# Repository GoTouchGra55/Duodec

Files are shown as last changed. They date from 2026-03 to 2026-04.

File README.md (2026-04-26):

# Duodec





A 12-key + 1 rotary encoder macropad built on
the RP2040-Zero, designed for developers and
students who live in their terminal.

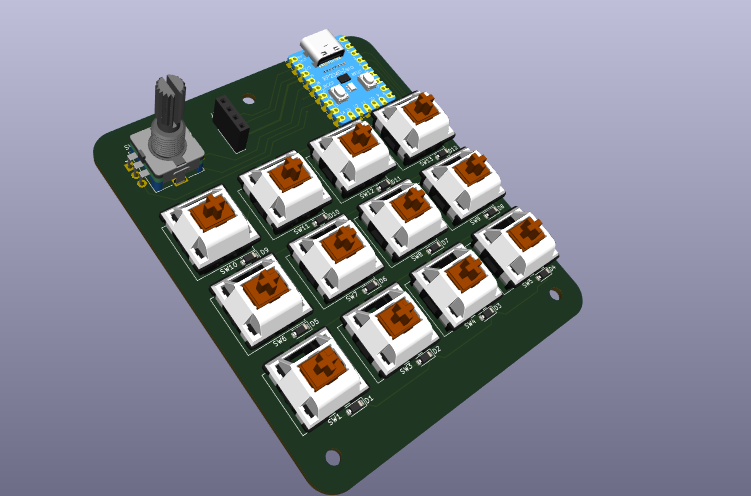
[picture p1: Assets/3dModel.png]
Duodec 3d model


---

## Overview

**Duodec** (Latin: _twelve_) is a compact, open-source macropad featuring 12 mechanical switches, a clickable rotary encoder, and an 128x32 OLED display. Built around the RP2040-Zero, it's fully programmable in Python.

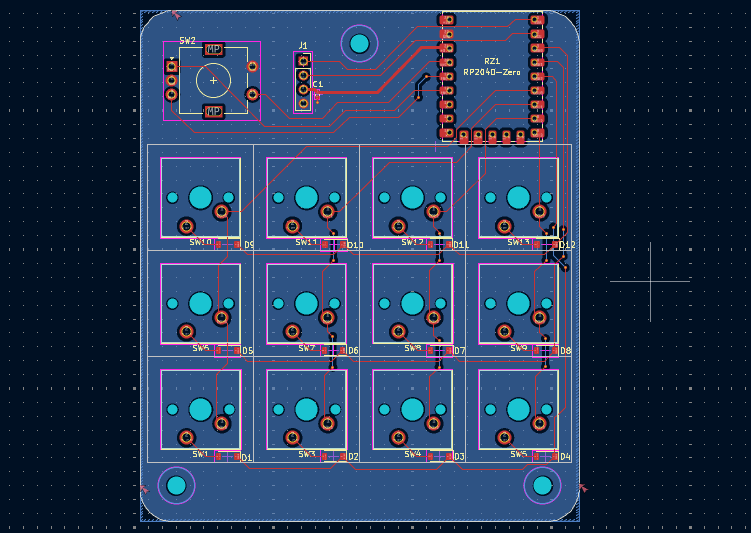
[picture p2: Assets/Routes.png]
PCB traces

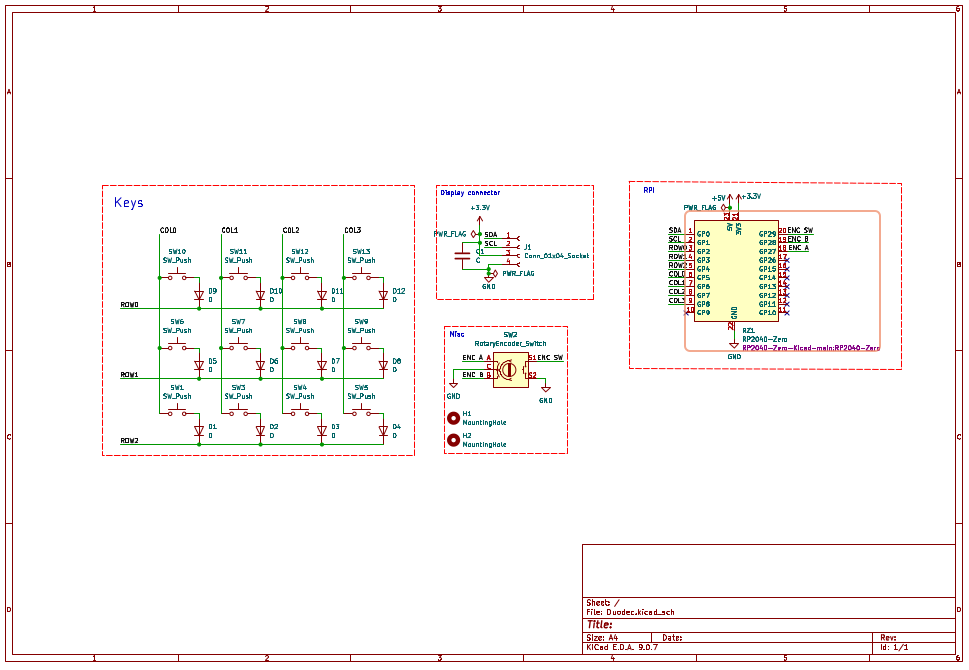
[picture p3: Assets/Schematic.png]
Schematic


---

## Working Demo

Here’s a quick demonstration of Duodec in action, showing key inputs, encoder rotation, and OLED layer switching.

Duodec demo

---

## Features

- 12x mechanical key switches in a 4x3 matrix
- 1x rotary encoder with push-button click
- 128x32 OLED display
- RP2040-Zero (RP2040 chip, USB-C)
- Fully programmable in Python
- Multiple layers for different workflows
- Custom 3D printed keys
- Open source hardware and software

## ⚠️ Important Wiring Note
Sorry about this ;-; but the OLED display requires **2-4kΩ 3.3V pull-up resistors** on both:
- SDA (I2C data line)
- SCL (I2C clock line)

Without these, the display will not function at all.

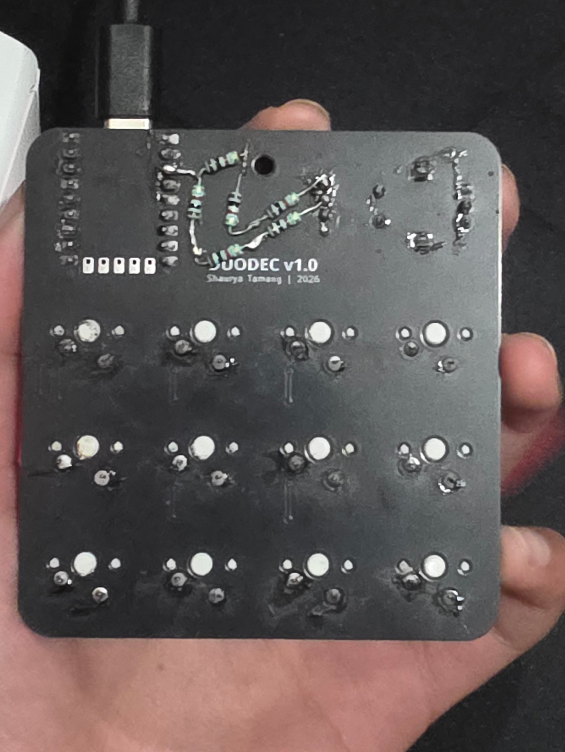
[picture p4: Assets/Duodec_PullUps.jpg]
PullUp Resistors


## Customization

1. Clone this repository
2. Open `src/main.py`
3. Modify keymaps (line 26)
4. Add your own shortcuts and layers
5. Flash to your RP2040-Zero

Be productive 🚀

## Contributing

Contributions are welcome!

If you'd like to improve Duodec, you can:
- Suggest new features or workflows
- Improve firmware or add new layers
- Fix bugs or optimize performance
- Enhance documentation or visuals

Please open an issue first to discuss major changes.

Pull requests should be clean, well-documented, and tested where possible.

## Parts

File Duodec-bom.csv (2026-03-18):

Name | Purpose | Cost Per Item (USD) | Quantity | Total (USD) | Link | Distributor
LEOBOG Graywood V4 Mechanical Linear Switch (Pack of 10) | To take user input in the deck | 3.39 | 2 | 6.78 | https://www.daraz.com.np//products/i170535424-s1189144506.html?urlFlag=true | Daraz Nepal
PCB and 3d Parts | PCB is the backbone for duodec and the 3d printed parts are for protection and ease of use | 17.59 | 1 | 17.59 | https://jlc3dp.com/shopcart/cart?source=3D&spm=Jlc3dp.Homepage.1009 | JLCPCB
Solder wire | To solder parts onto the pcb | 1.22 | 1 | 1.22 | https://www.daraz.com.np//products/i123779146-s1033610157.html?urlFlag=true | Daraz Nepal
Soldering iron | Used to solder various electrical components | 2.69 | 1 | 2.69 | https://www.daraz.com.np/products/60w-combo-kit-soldering-iron-rod-iron-wire-flux-i130121110-s1038004751.html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 | Daraz Nepal
SOD-123 SMD Switching Diode | Used to prevent ghosting in keyboards | 4.39 | 1 | 4.39 | https://www.daraz.com.np//products/i416542528-s1792465060.html?urlFlag=true&tradePath=%2CcartPriceDrop%2Ccart | Daraz Nepal
Rotary Encoder | To obtain rotary and click values for precise controls | 0.67 | 1 | 0.67 | https://www.daraz.com.np//products/i140566281-s1074190810.html?urlFlag=true&tradePath=%2CcartPriceDrop%2Ccart | Daraz Nepal
128x32 OLED display | To display various options for Duodec | 4.76 | 1 | 4.76 | https://www.daraz.com.np//products/i129083637-s1037084826.html?urlFlag=true&tradePath=%2CcartPriceDrop%2Ccart | Daraz Nepal
RP-2040 Zero | Control the overall function of my custom macropad. | 4.76 | 1 | 4.76 | https://www.daraz.com.np/products/rp2040-zero-rp2040-for-raspberry-pi-microcontroller-i149575151-s1104086822.html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 | Daraz Nepal

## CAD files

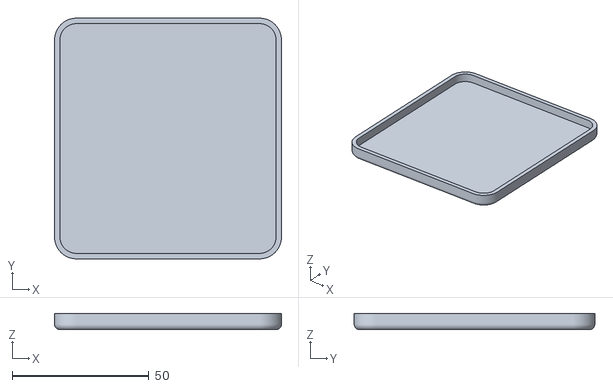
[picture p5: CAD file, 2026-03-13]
CAD files/Duodec.stl
83.0 x 88.0 x 6.00

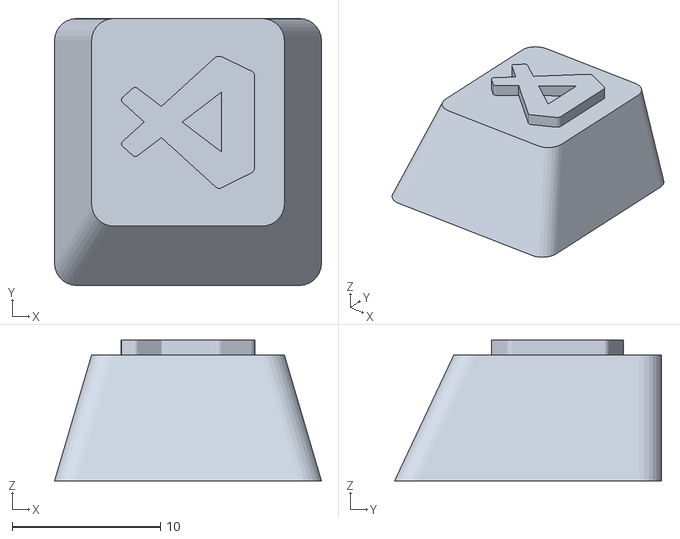
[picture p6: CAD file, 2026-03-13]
CAD files/Keycaps/vscode.stl
18.0 x 18.0 x 9.50

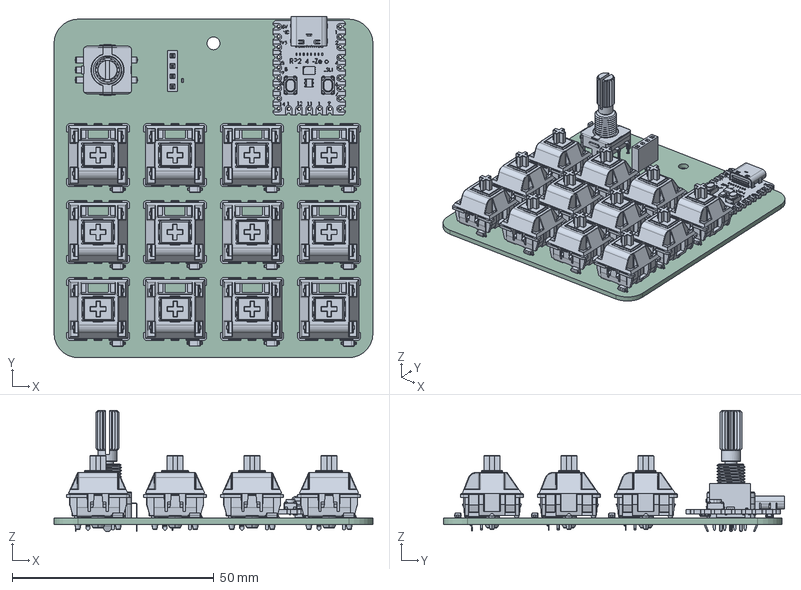
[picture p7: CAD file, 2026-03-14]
KiCAD files/Duodec.step
79.0 x 84.6 x 30.1 mm
C_0402_1005Metric
D_SOD-123 x 12
SW_Cherry_MX_PCB x 12
RP2040-ZERO-WAVESHARE without headers
PinSocket_1x04_P2.54mm_Vertical
EC11_Rotary_Encoder_Switched
Duodec_PCB

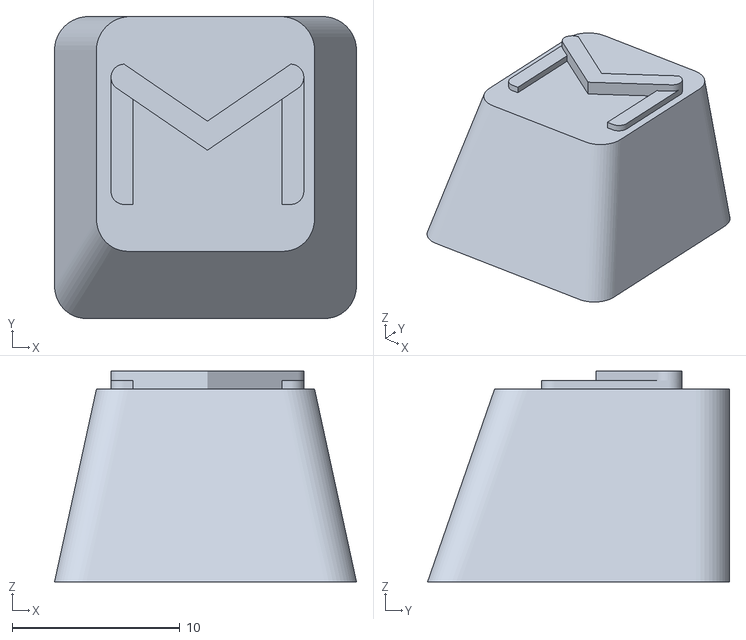
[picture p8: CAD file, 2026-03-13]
CAD files/Keycaps/gmail_mx_key_cap.stl
18.0 x 18.0 x 12.6

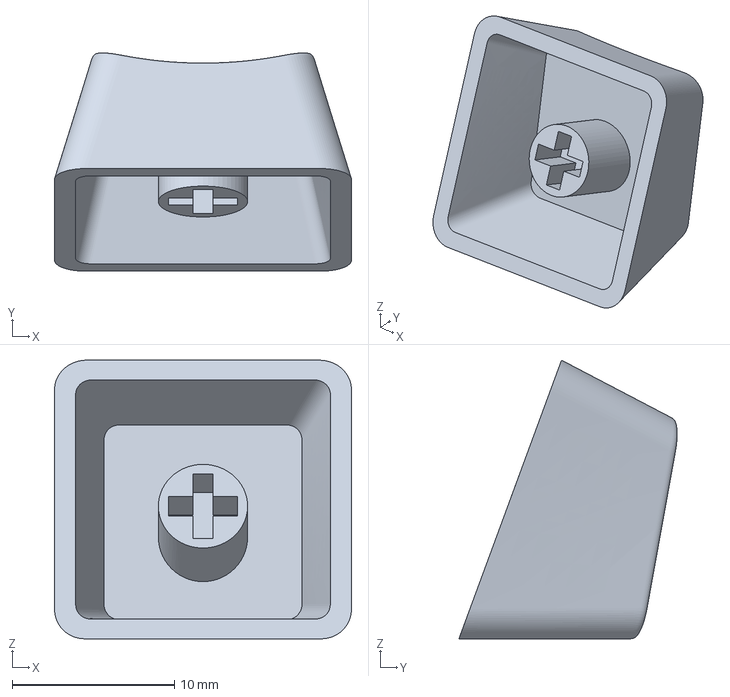
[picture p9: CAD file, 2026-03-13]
CAD files/Keycaps/Keycap.3mf
18.3 x 13.4 x 17.2 mm

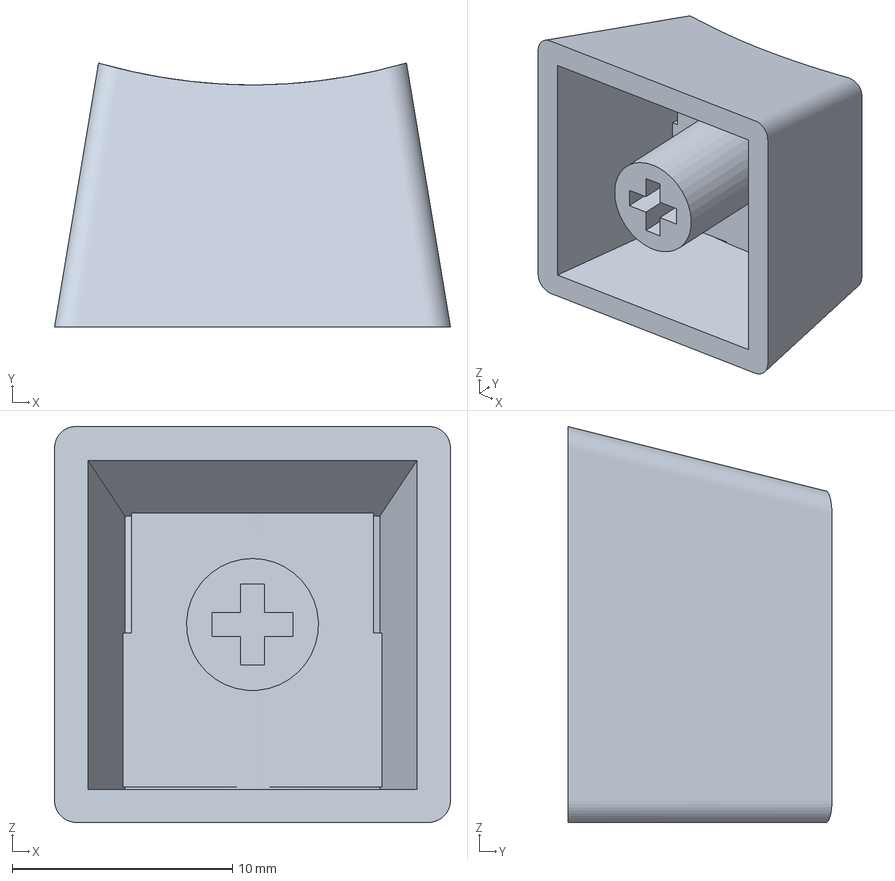
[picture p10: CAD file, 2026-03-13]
CAD files/Keycaps/creeper key.3MF
18.0 x 12.0 x 18.0 mm

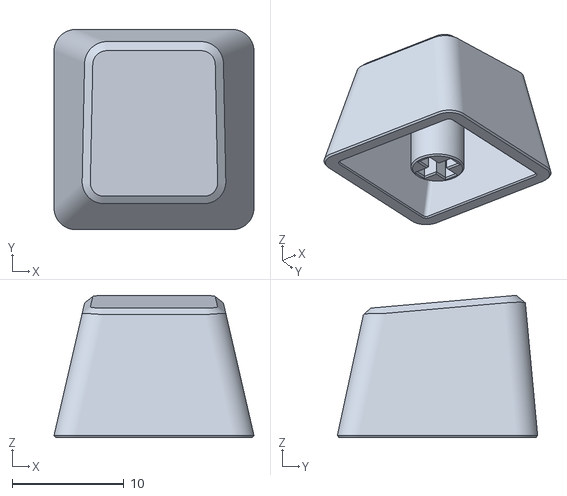
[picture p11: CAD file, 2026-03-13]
CAD files/Keycaps/Basic_round_5.stl
17.9 x 17.9 x 12.7

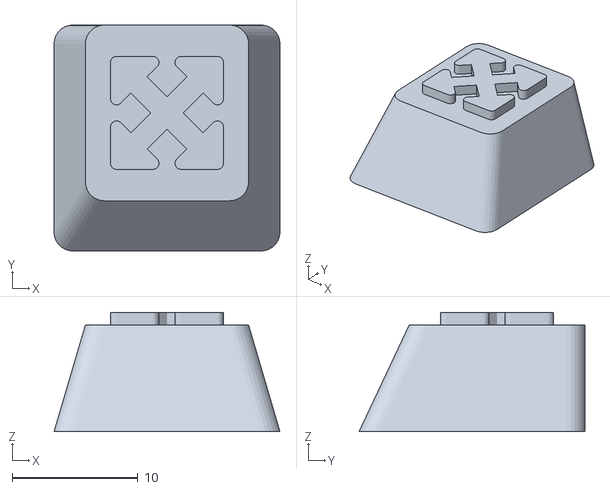
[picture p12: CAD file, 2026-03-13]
CAD files/Keycaps/maximize-solid.stl
18.0 x 18.0 x 9.50

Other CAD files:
CAD files/Keycaps/pause-solid.stl
CAD files/Keycaps/terminal-solid.stl
CAD files/Keycaps/play-solid.stl

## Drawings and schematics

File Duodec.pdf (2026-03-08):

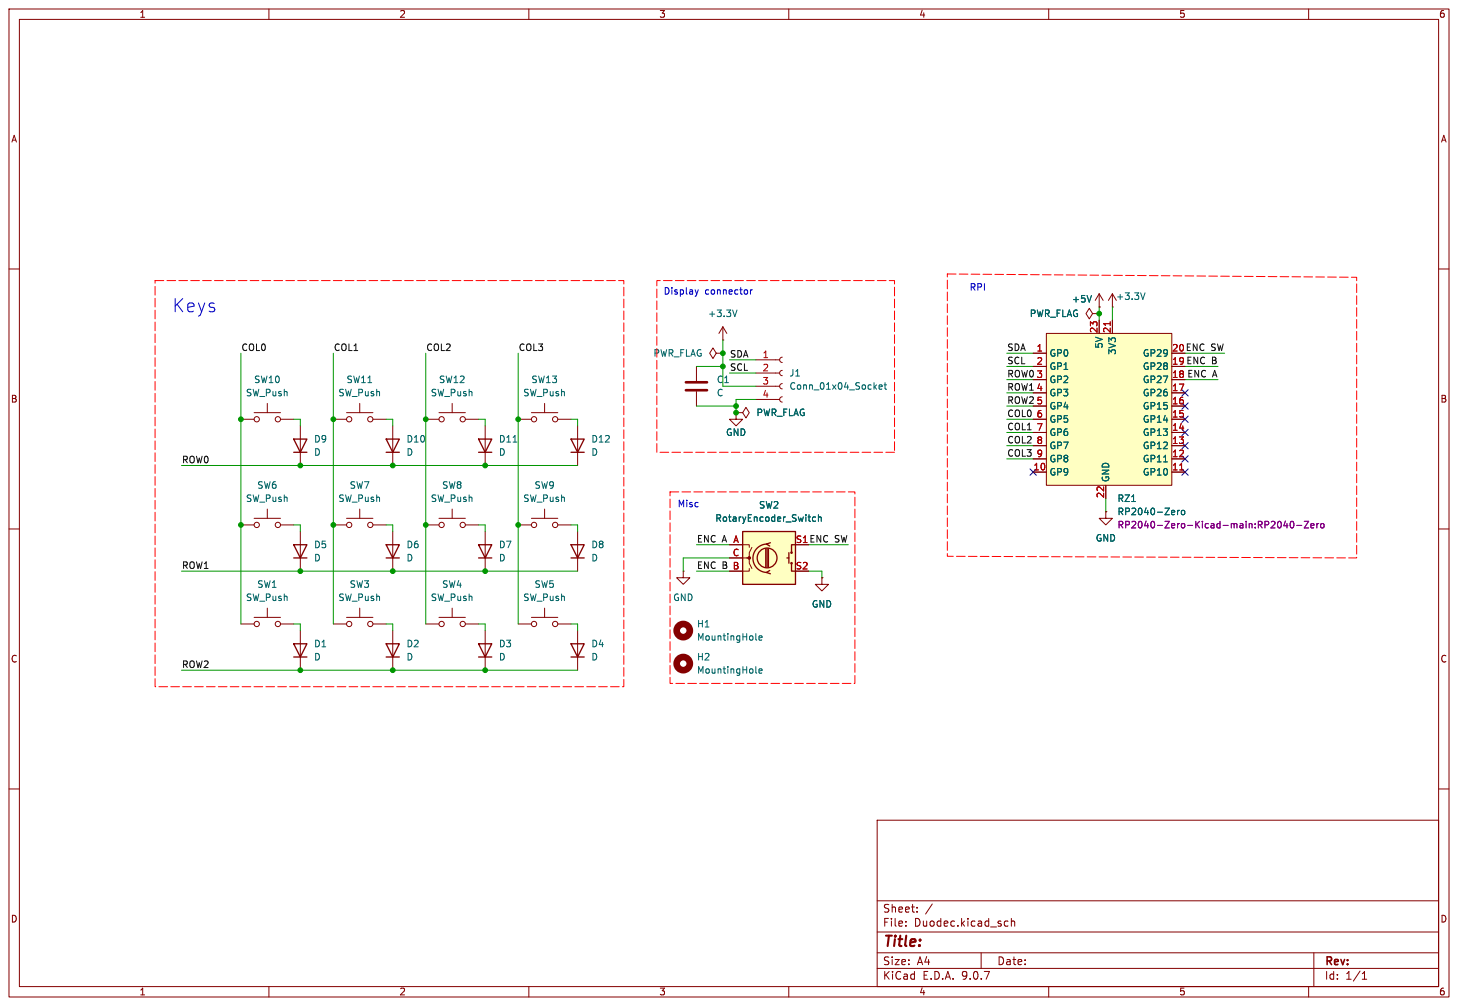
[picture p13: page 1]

Id: 1/1 Title: File: Duodec.kicad_sch Sheet: / H2 MountingHole D2 D

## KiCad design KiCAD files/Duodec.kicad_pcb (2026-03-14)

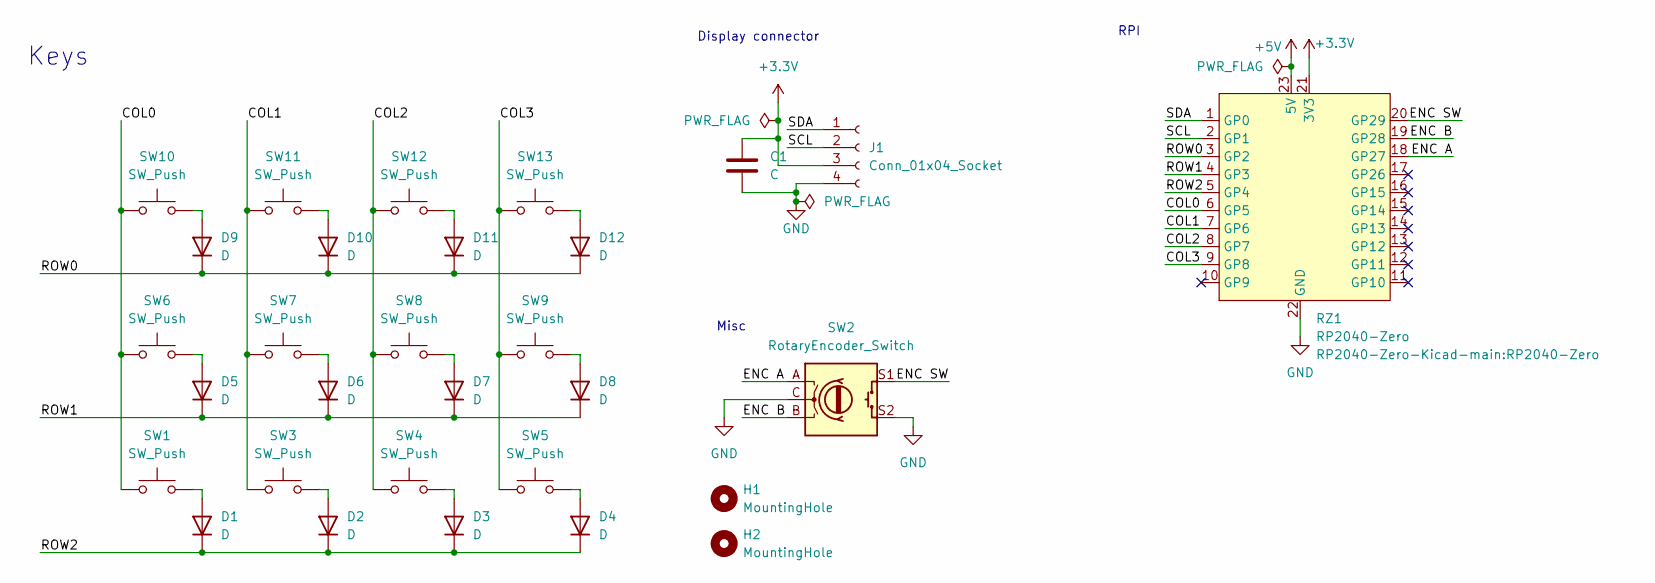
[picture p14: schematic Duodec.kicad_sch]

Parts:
C1: C; C_0402_1005Metric
D1, D2, D3, D4, D5, D6, D7, D8, D9, D10, D11, D12: D; D_SOD-123
H1, H2: MountingHole; MountingHole_3.2mm_M3
J1: Conn_01x04_Socket; PinSocket_1x04_P2.54mm_Vertical
RZ1: RP2040-Zero
SW1, SW3, SW4, SW5, SW6, SW7, SW8, SW9, SW10, SW11, SW12, SW13: SW_Push; SW_Cherry_MX_PCB_1.00u
SW2: RotaryEncoder_Switch; RotaryEncoder_Duodec

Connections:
+3.3V: C1.1, J1.3, RZ1.21 (3V3)
+5V: RZ1.23 (5V)
/COL0: RZ1.6 (GP5), SW1.1, SW6.1, SW10.1
/COL1: RZ1.7 (GP6), SW3.1, SW7.1, SW11.1
/COL2: RZ1.8 (GP7), SW4.1, SW8.1, SW12.1
/COL3: RZ1.9 (GP8), SW5.1, SW9.1, SW13.1
/ENC A: RZ1.18 (GP27), SW2.A
/ENC B: RZ1.19 (GP28), SW2.B
/ENC SW: RZ1.20 (GP29), SW2.S1
/ROW0: D9.1 (K), D10.1 (K), D11.1 (K), D12.1 (K), RZ1.3 (GP2)
/ROW1: D5.1 (K), D6.1 (K), D7.1 (K), D8.1 (K), RZ1.4 (GP3)
/ROW2: D1.1 (K), D2.1 (K), D3.1 (K), D4.1 (K), RZ1.5 (GP4)
/SCL: J1.2, RZ1.2 (GP1)
/SDA: J1.1, RZ1.1 (GP0)
GND: C1.2, J1.4, RZ1.22 (GND), SW2.C, SW2.S2
unnamed: D1.2 (A), SW1.2
unnamed: D2.2 (A), SW3.2
unnamed: D3.2 (A), SW4.2
unnamed: D4.2 (A), SW5.2
unnamed: D5.2 (A), SW6.2
unnamed: D6.2 (A), SW7.2
unnamed: D7.2 (A), SW8.2
unnamed: D8.2 (A), SW9.2
unnamed: D9.2 (A), SW10.2
unnamed: D10.2 (A), SW11.2
unnamed: D11.2 (A), SW12.2
unnamed: D12.2 (A), SW13.2

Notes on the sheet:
Keys
Misc
Display connector
RPI

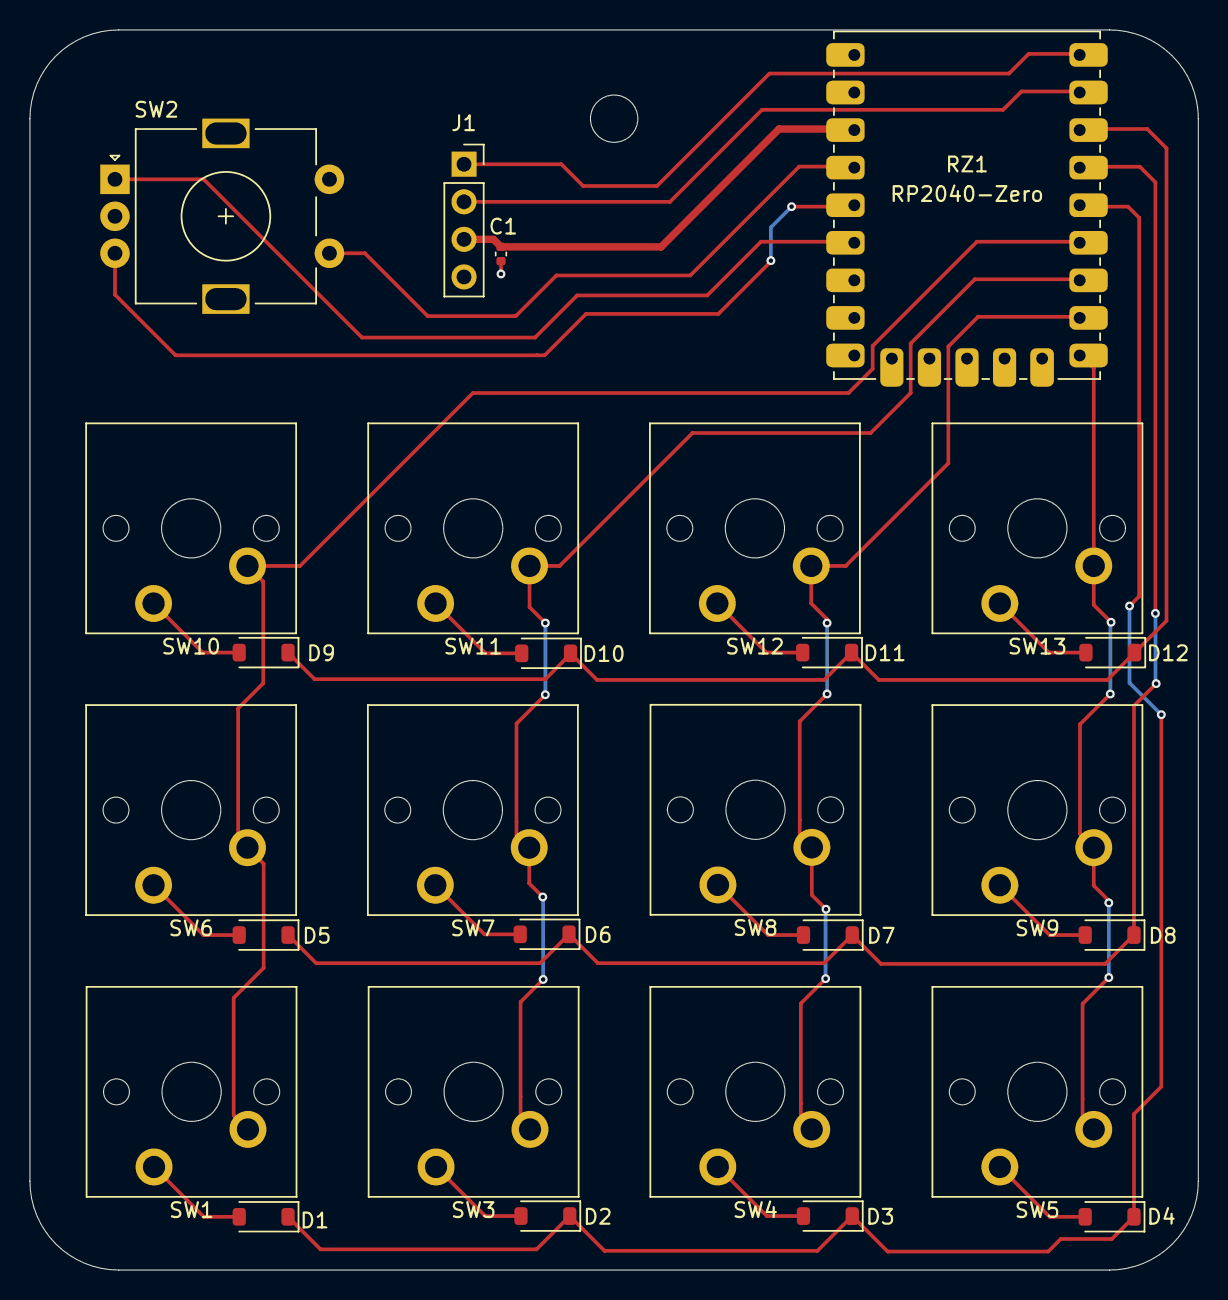
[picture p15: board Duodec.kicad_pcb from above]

Board: 2 copper layers, 79.0 x 83.8 mm, 29 parts (0 on the bottom side), 26 nets.

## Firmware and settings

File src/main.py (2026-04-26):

import time
import busio
import board
import usb_hid
import digitalio
import adafruit_ssd1306

from adafruit_hid.consumer_control import ConsumerControl
from adafruit_hid.consumer_control_code import ConsumerControlCode
from kmk.kmk_keyboard import KMKKeyboard
from kmk.scanners import DiodeOrientation
from kmk.modules.layers import Layers
from kmk.keys import KC

# kmk setup
Duodec = KMKKeyboard()

Duodec.col_pins = (board.GP5, board.GP6, board.GP7, board.GP8)
Duodec.row_pins = (board.GP2, board.GP3, board.GP4)
Duodec.diode_orientation = DiodeOrientation.COL2ROW

layers = Layers()
Duodec.modules.append(layers)

# Add your custom keymaps here and dont forget to add stuff to the modes list below!
keyMap = [
    # HOME
    [
        KC.LCTL(KC.LALT(KC.L)), KC.LCTL(KC.LALT(KC.S)), KC.LCTL(KC.LALT(KC.B)), KC.LCTL(KC.LALT(KC.G)),
        KC.LALT(KC.H), KC.LCTL(KC.LALT(KC.C)), KC.LCTL(KC.LALT(KC.K)), KC.LCTL(KC.LALT(KC.T)),
        KC.LCTL(KC.LALT(KC.M)), KC.LCTL(KC.LALT(KC.O)), KC.LCTL(KC.LALT(KC.P)), KC.LCTL(KC.LALT(KC.V))
    ],

    # BRAVE (I'm a brave user :3)
    [
        KC.NO, KC.NO, KC.NO, KC.NO,
        KC.NO, KC.NO, KC.NO, KC.NO,
        KC.NO, KC.NO, KC.NO, KC.NO
    ],

    # DEV
    [
        KC.NO, KC.NO, KC.NO, KC.NO,
        KC.NO, KC.NO, KC.NO, KC.NO,
        KC.NO, KC.NO, KC.NO, KC.NO
    ],

    # MEDIA
    [
        KC.NO, KC.NO, KC.NO, KC.NO,
        KC.NO, KC.NO, KC.NO, KC.NO,
        KC.NO, KC.NO, KC.NO, KC.NO
    ]
]

Duodec.keymap = keyMap

# Edit this according to your keymaps
modes = ["HOME", "BROWSER", "DEV", "MEDIA"] 

# Display stuff
i2c = busio.I2C(board.GP1, board.GP0)
oled = adafruit_ssd1306.SSD1306_I2C(128, 32, i2c)

cc = ConsumerControl(usb_hid.devices)

# Encoder stuff
a = digitalio.DigitalInOut(board.GP27)
b = digitalio.DigitalInOut(board.GP28)
btn = digitalio.DigitalInOut(board.GP29)

a.switch_to_input(pull=digitalio.Pull.UP)
b.switch_to_input(pull=digitalio.Pull.UP)
btn.switch_to_input(pull=digitalio.Pull.UP)

current_layer = 0
last_a = a.value

# State
muted = False
last_btn = btn.value
last_draw = None

# Layer Control
def set_layer(index):
    global current_layer
    current_layer = index % len(modes)
    Duodec.active_layers = [current_layer]

# init layer
set_layer(0)

# Switch Layer
def read_encoder():
    global last_a

    a_state = a.value
    b_state = b.value

    if a_state != last_a:
        if a_state:
            if b_state:
                set_layer(current_layer - 1)  # counter-clockwise
            else:
                set_layer(current_layer + 1)  # clockwise

        last_a = a_state

# Encoder Btn 
def read_button():
    global muted, last_btn

    if last_btn and not btn.value:
        muted = not muted
        cc.send(ConsumerControlCode.MUTE)

    last_btn = btn.value

# Display 
def draw():
    global last_draw

    display_value = "MUTED" if muted else "ACTIVE"
    screen = modes[current_layer] + display_value

    if screen == last_draw:
        return

    oled.fill(0)
    oled.text("DUODEC v1", 0, 0, 1)
    oled.text("MODE: " + modes[current_layer], 0, 10, 1)
    oled.text("STATUS: " + display_value, 0, 20, 1)
    oled.show()

    last_draw = screen

def after_matrix_scan():
    read_encoder()
    read_button()
    draw()

Duodec.after_matrix_scan = after_matrix_scan()

if __name__ == "__main__":
    Duodec.go()

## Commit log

2026-03-13 Add CAD files and organize structure
    [Basic_round_5.stl, Duodec.stl, Keycap.3mf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]
2026-03-13 Add BOM
    [BOM.csv]
2026-03-14 Add kicad files
    [Duodec.kicad_pcb, Duodec.kicad_sch, Duodec.step]
2026-03-18 Modify cost for PCB and 3D parts entry
    Updated the cost per item for PCB and 3D parts.
    [Duodec-bom.csv]
2026-03-18 Correct PCB and 3D Parts unit price
    Updated the unit price of PCB and 3D Parts from $30.76 to $17.59.

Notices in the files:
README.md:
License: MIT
